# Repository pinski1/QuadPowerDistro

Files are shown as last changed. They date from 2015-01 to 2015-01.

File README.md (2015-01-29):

#Quadcopter Power Distribution & Sensor board#

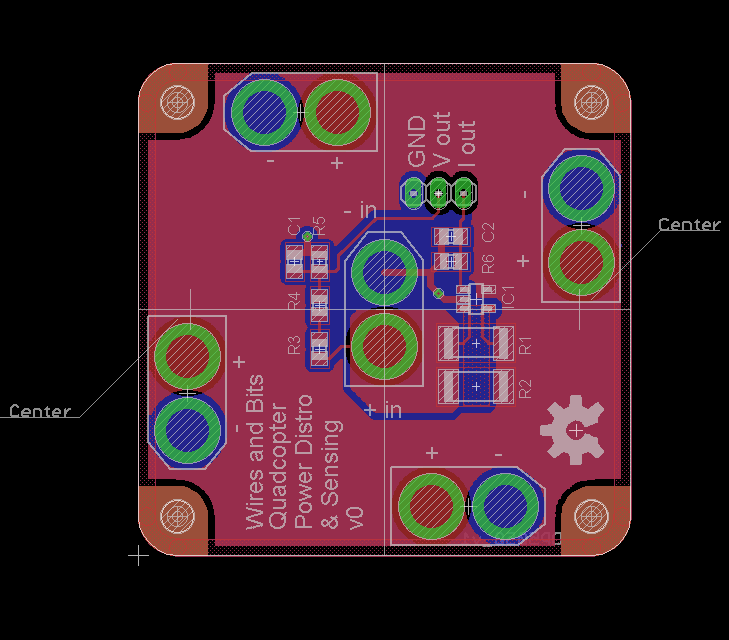
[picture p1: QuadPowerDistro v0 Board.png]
Image of QuadPowerDistro board


This board will simplify your power distribution on your small to medium sized quadcopter. IT includes a built in current sensor to reduce weight and the hassle of adding an external one.

See the [schematic](QuadPowerDistro v0 Schematic.png) for more information.

##Dimensions##

* The PCB is 50mm by 50mm and 1.6mm thick.
* The corners have a 4mm radius.
* The mounting holes are 3.2mm in diameter and are 4mm from the edges.

##Buying##
This board can be bought, assembled for your quadcopter on Tindie in 3 flavours.



##License##

<br /><span xmlns:dct="http://purl.org/dc/terms/" property="dct:title">QuadcopterPowerDistro</span> by <span xmlns:cc="http://creativecommons.org/ns#" property="cc:attributionName">Pinski1</span> is licensed under a <a rel="license" href="http://creativecommons.org/licenses/by/4.0/">Creative Commons Attribution 4.0 International License</a>.

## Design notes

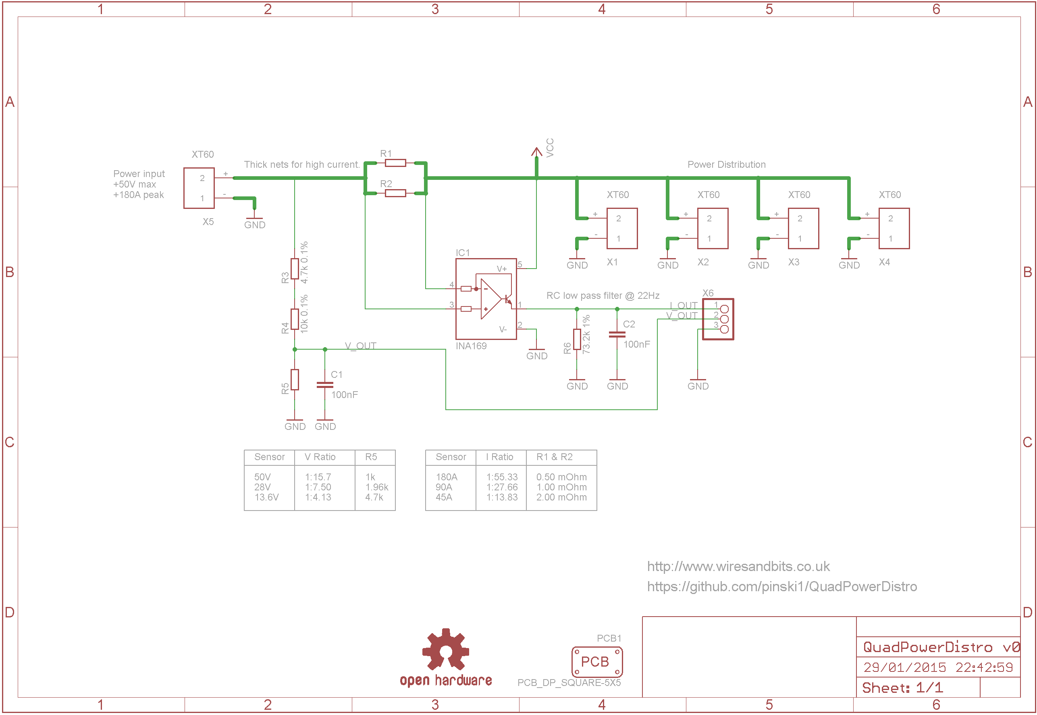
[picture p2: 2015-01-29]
QuadPowerDistro v0 Schematic.png

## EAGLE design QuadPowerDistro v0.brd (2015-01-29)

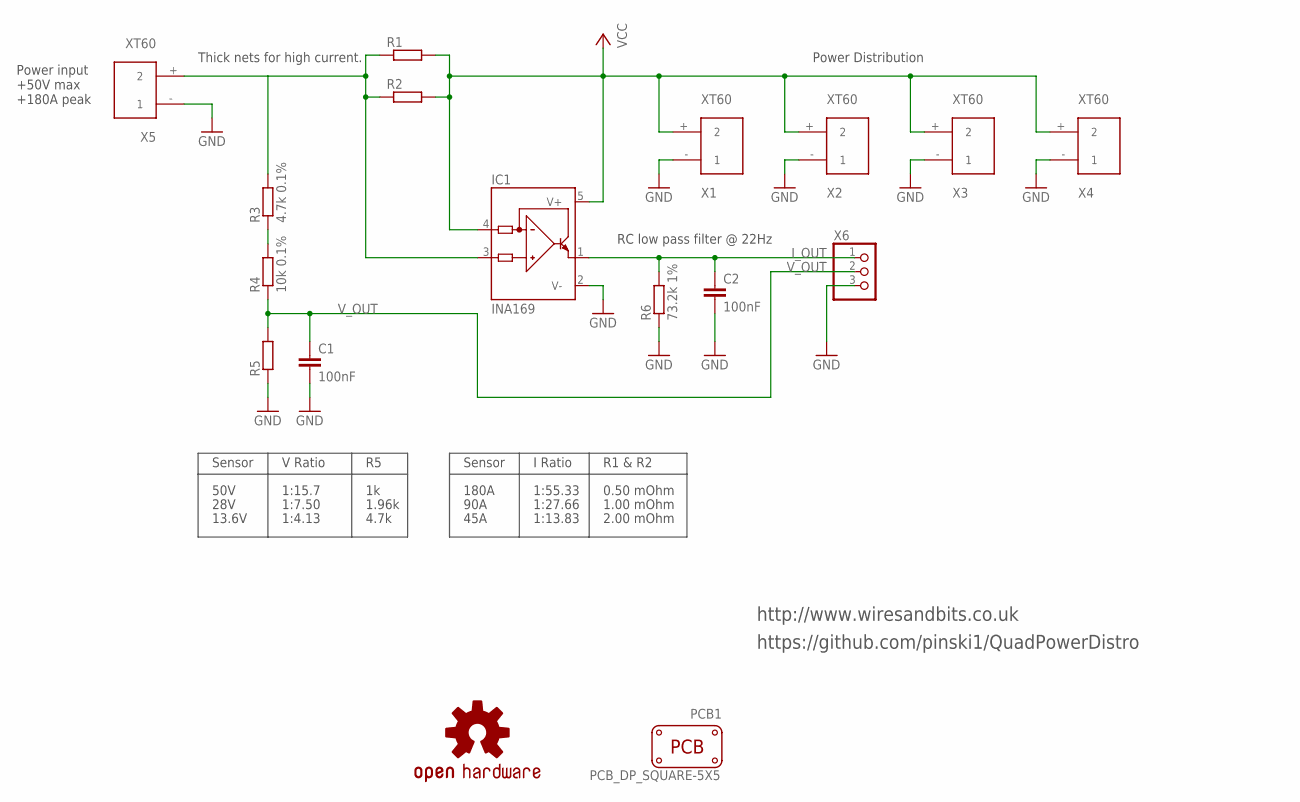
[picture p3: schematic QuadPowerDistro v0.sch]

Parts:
C1, C2: 100nF; C0805; MPN 02016D104KAT2A
IC1: INA169; SOT23-5; MPN INA169NA/250G4
LOGO1: OSHW-LOGOL; OSHW-LOGO-L
PCB1: PCB_DP_SQUARE-5X5; DP5050_V1
R1, R2: R-EU_R2512; R2512
R3: 4.7k 0.1%; R0805; MPN RR1220P-472-B-T5
R4: 10k 0.1%; R0805; MPN RR1220P-103-B-T5
R5: R-EU_R0805; R0805
R6: 73.2k 1%; R0805
X1, X2, X3, X4, X5: XT60
X6: PINHD-1X3; 1X03

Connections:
GND: C1.2, C2.2, IC1.2 (V-), R5.1, R6.1, X1.- (1), X2.- (1), X3.- (1), X4.- (1), X5.- (1), X6.3
I_OUT: C2.1, IC1.1 (OUT), R6.2, X6.1
VCC: IC1.4 (IN-), IC1.5 (V+), R1.2, R2.2, X1.+ (2), X2.+ (2), X3.+ (2), X4.+ (2)
VCC_RAW: IC1.3 (IN+), R1.1, R2.1, R3.2, X5.+ (2)
V_OUT: C1.1, R4.1, R5.2, X6.2
V_SEN_HIGH: R3.1, R4.2

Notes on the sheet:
V Ratio
Sensor
50V
13.6V
4.7k
1:15.7
1:4.13
R1 & R2
180A
90A
0.50 mOhm
1.00 mOhm
45A
2.00 mOhm
28V
1.96k
1:7.50
I Ratio
1:55.33
1:13.83
1:27.66
RC low pass filter @ 22Hz
Power Distribution
Thick nets for high current.
Power input +50V max +180A peak
http://www.wiresandbits.co.uk
https://github.com/pinski1/QuadPowerDistro

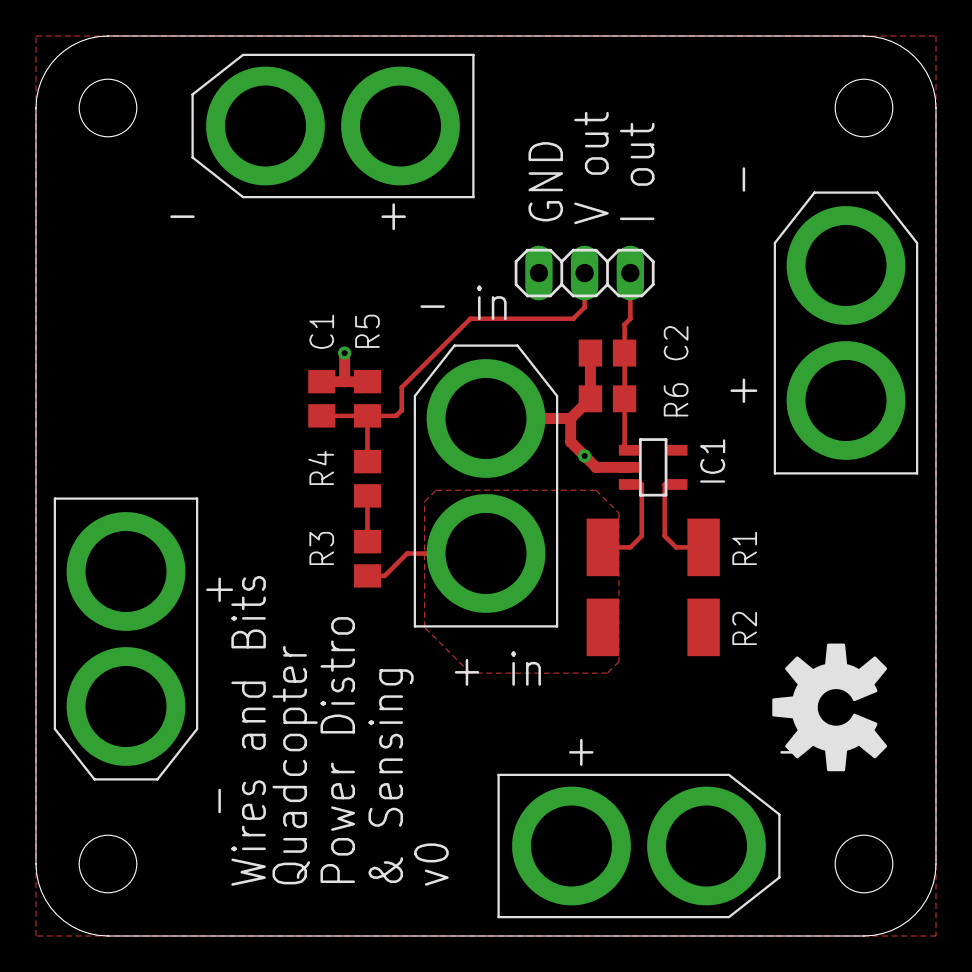
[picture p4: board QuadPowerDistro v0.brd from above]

Board: 2 copper layers, 50.0 x 50.0 mm, 17 parts (0 on the bottom side), 6 nets.

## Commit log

2015-01-29 Initial commit.
    [Rev 1.brd, Rev 1.sch]
2015-01-29 File updates
    Making the filenames clearer.
    [QuadPowerDistro v0.brd, QuadPowerDistro v0.sch]
2015-01-29 Adding more information.
    [QuadPowerDistro v0.brd, QuadPowerDistro v0.sch]

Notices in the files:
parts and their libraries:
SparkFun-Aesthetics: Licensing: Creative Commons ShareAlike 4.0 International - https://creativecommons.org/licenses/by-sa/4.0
